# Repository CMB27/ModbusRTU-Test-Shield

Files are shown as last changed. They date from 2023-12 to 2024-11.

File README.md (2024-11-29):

# ModbusRTU Test Shield
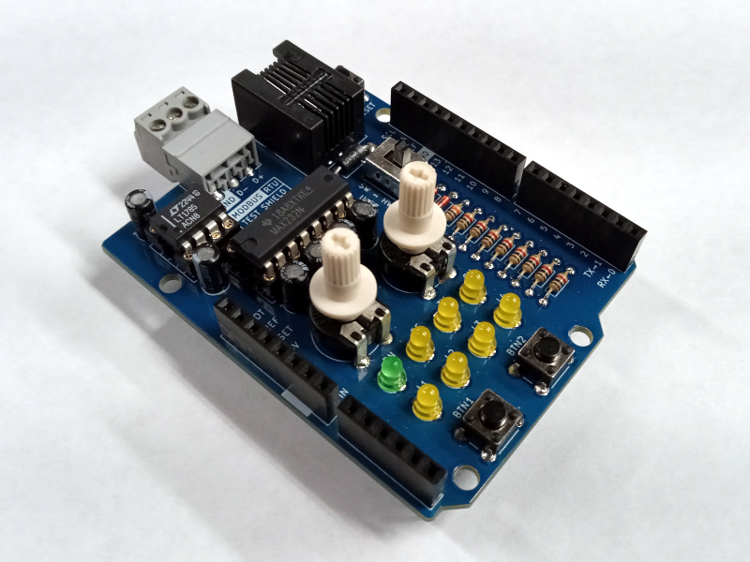
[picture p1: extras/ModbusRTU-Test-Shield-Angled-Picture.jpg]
ModbusRTU Test Shield Picture


A shield for Arduino boards that provides an RS-485 transceiver, RS-232 transceiver, and a selection of buttons, lights, and knobs.
This board was designed to aid in testing the [ModbusRTUSlave](https://github.com/CMB27/ModbusRTUSlave) and [ModbusRTUMaster](https://github.com/CMB27/ModbusRTUMaster) libraries.

- This shield is designed to work with both 5V and 3.3V Arduino boards.
- A 3-position removable screw terminal is used as the RS-485 interface.
- A RJ12 connector is used as the RS-232 inteface. The pinout of this connector is designed to make it compatible with Automation Direct products.
- The potentiomter knobs can be easily removed so you can stack other shields on top of this one.
- There is a switch to easily change between using a `HardwareSerial` port or a `SoftwareSerial` port.
- The selected serial port is connected to both the RS-485 and RS-232 transceivers, so not confugration changes are needed to switch between them.

> [!NOTE]
> This design is distributed WITHOUT ANY EXPRESS OR IMPLIED WARRANTY, INCLUDING OF MERCHANTABILITY, SATISFACTORY QUALITY AND FITNESS FOR A PARTICULAR PURPOSE.
> 
> This board is designed to use only one serial interface (RS-485 or RS-232) at a time.
> Attempting to use both at the same time is unlikely to damage the board, but could lead to unexpected behavior.

### Pinouts
#### Arduino Pin Usage
| Pin | Function | pinMode |
|-----|---|---|
| 0 | HardwareSerial RX | INPUT (Set by HardwareSerial) |
| 1 | HardwareSerial TX | OUTPUT (Set by HardwareSerial) |
| 2 | Button1 (BTN1) | INPUT_PULLUP |
| 3 | Button2 (BTN2) | INPUT_PULLUP |
| 5 | LED1 (L1) | OUTPUT |
| 6 | LED1 (L2) | OUTPUT |
| 7 | LED1 (L3) | OUTPUT |
| 8 | LED1 (L4) | OUTPUT |
| 10  | SoftwareSerial RX | INPUT (Set by SoftwareSerial) |
| 11  | SoftwareSerial TX | OUTPUT (Set by SoftwareSerial) |
| 13  | Driver Enable (DE) | OUTPUT (set by ModbusRTUSlave or ModbusRTUMaster) |
| A0  | Potentiometer1 (POT1) | INPUT |
| A1  | Potentiometer2 (POT2) | INPUT |

_Unused Pins: 4, 9, 12, A2, A3, A4, A5_

#### RS-485 Interface (J5)
| Pin | Function  | Electrical Type |
|-----|---|---|
| 1 | RS-485 D+ | Bidirectional |
| 2 | RS-485 D- | Bidirectional |
| 3 | GND | Passive |

#### RS-232 Interface (J6)
| Pin | Function  | Electrical Type |
|-----|---|---|
| 1 | GND | Passive |
| 2 | 5V | Power Output |
| 3 | RS-232 RX | Input |
| 4 | RS-232 TX | Output |
| 5 | VBUS | Power Input |
| 6 | GND | Passive |

### Documentation
- [Schematic](ModbusRTU-Test-Shield.pdf)
- [KiCAD Source Files](src)
- [STEP 3D Model](extras/ModbusRTU-Test-Shield.step)

## Components

### Circuit Board
#### Specifications
- Board Length: __68.58mm__
- Board Width: __53.34mm__
- Board Thickness: __1.6mm__
- Substrate Material: __FR4__
- Copper Layers: __2__
- Copper Thickness: __1oz__
- Soldermask Color: __Any__ (Blue Suggested)
- Smallest Hole Diameter: __0.6mm__
- Smallest Trace Width: __0.2mm__ (7.8mil)
- Smallest Trace Spacing: __0.2mm__ (7.8mil)

#### Suppliers
Below are some circuit board manufacturers I have used in the past.
Generally you will need to upload the upload the [gerber and drill files](gerbers) to their websites in a .zip folder.

- [OSH Park](https://oshpark.com) is a US based circuit board fabrication service.
  They tend to be more expensive than other manufacturers and the number of options they give you are limited (If you use this manufacturer, I hope you like purple).

- [Seeed Studio Fusion](https://www.seeedstudio.com/fusion_pcb.html) makes circuit boards in China.
  They have a lot of options when ordering; please refer to the [specifications](#specifications) above when making your choices.
  They do have a circuit board assembly service as well, but I am not especially familiar with it.

### Purchase Components

| Reference | Qty | Manufacturer | Part Number | Description | Notes |
|---|----:|---|---|---|---|
| C1-C6 | 6 | KEMET | ESS105M050AB2EA | 1uF Aluminum Electrolytic Capacitor | |
| D1-D4, D6-D8 | 7 | Würth Elektronik | 151031YS06000 | Yellow LED | |
| D5 | 1 | Würth Elektronik | 151031VS04000 | Green LED | |
| D9, D10 | 2 | Vishay | BAT43-TAP | Schottky Diode | |
| D11 | 1 | Vishay | SB260S-E3/54 | Schottky Diode | |
| J1-J4 | 1 | SparkFun Electronics | PRT-11417	 | Stacking Socket Header Kit | This kit contains all the connectors for the Arduino interface. |
| J5 | 1 | Phoenix Contact | 5434557 | 3-Position Terminal Block Plug | |
| J6 | 1 | Amphenol ICC (FCI) | 87180-066LF | RJ12 Jack | |
| R1-R8 | 8 | Stackpole Electronics  | CFM14JT1K00 | 1K Ohm Resistor | These are generic 1K Ohm resistors; smilarly sized components of the same value should work.  |
| R9 | 1 | Stackpole Electronics  | CFM14JT10K0 | 10K Ohm Resistor | This is a generic 10K Ohm resistor; a smilarly sized component of the same value should work. |
| RV1, RV2 | 2 | Piher/Amphenol | PT10MV10-103A2020-E-S | 10K Ohm Potentiometer | |
| RV1, RV2 | 2 | Piher/Amphenol | JPEPL6052INI | Potentiometer Knob | |
| SW1-SW3 | 3 | Omron | B3F-1020 | 6mm Pushbutton Switch | This is a generic 6mm pushbutton switch. Feel free to substitute. |
| SW4 | 1 | C&K | OS202011MS2QN1 | DPDT Slide Switch | |
| U1 | 1 | Texas Instruments | SN65HVD3082EP | RS-485 Half-Duplex Transceiver | |
| U2 | 1 | Texas Instruments | MAX232N | RS-232 Transceiver | |
| XJ5 | 1 | Phoenix Contact | 5430438 | 3-Position Terminal Block Header | |
| XU1 | 1 | Assmann WSW Components | AR 08-HZL/01-TT | 8-Position DIP Socket | |
| XU2 | 1 | Assmann WSW Components | AR 16-HZL/01-TT | 16-Position DIP Socket | |

You may also want termination resistors for RS-485; 120 Ohms is a common value.

#### Suppliers
Below are some electronics suppliers I have used in the past:

- [Digi-Key](https://www.digikey.com/) is my usual go-to supplier for electronic components.
  Their website makes it pretty easy to sort through parts.

- [Mouser](https://www.mouser.com/) is very similar to Digi-Key in a lot of ways.
  They sometimes have better pricing, and they have excellent customer support.

- [Newark](https://www.newark.com/) tends to have a bit different selection than Digi-Key and Mouser, especially in the area of connectors.

- [Octopart](https://octopart.com/) is not a supplier per se; it is essenitally an electronic component search engine.
  This can be a very helpful tool when looking for parts, especially somewhat unusual ones, like extended socket headers.

All of these suppliers have a feature on their respective websites where you can upload a spreadsheet file, such as [ModbusRTU-Test-Shield-BOM.csv](ModbusRTU-Test-Shield-BOM.csv), to populate the cart or find parts.

## Assembly

### Tools and Supplies
| Item | Optional | Notes |
|---|---|---|
| Soldering Iron | No | Make sure you use a good quality soldering iron. A poor quality soldering iron will give you a miserable soldering experience. |
| Flush Cutters | No | These are used to trim component leads. |
| Flux Core Solder  | No | Leaded solder is easier to work with, but lead-free solder is better for the environment. |
| Solder Flux | Yes | Extra flux will make the solder flow better. I don't usually use it when through-hole soldering, but it can be helpful. |
| Solder Wick | Yes | This is used to remove solder from places you don't want it. |
| Solder Sucker | Yes | If you need to de-solder a component, this, along with solder wick, is the tool you want. This can quickly remove most of the solder from a joint. |
| Arduino Shield | Yes | This can be used to hold the stacking socket headers in place while being assembled. |
| Isopropyl Alcohol | Maybe | This is used to remove flux. It is not needed if you are using no-clean flux. |
| Dish Soap | Maybe | This is used to remove flux residue. It is not needed if you are using no-clean flux. |

**Note on Flux**  
Traditional flux if left on the assembled circuit board could cause some serious issues.
It can potentially cause shorts or significant [parasitic capacitance](https://en.wikipedia.org/wiki/Parasitic_capacitance).
It is also somewhat corrosive and can, over time, damage your circuit board.
This sort of flux must be cleaned off the board after assembly.  
To address these issues there are no-clean fluxes, that can be left on the circuit board assembly and are unlikly to cause these issues.
There are also water-soluble fluxes that can be cleaned off with hot water, though I have found that some isopropyl alcohol can speed up the process.
There are also fluxes that are both no-clean and water soluble; this is what I like to use.

### Assembly Steps
Except for the socketed parts, all the components are placed on the front side of the board and solderd on the back side of the board.
These steps go through soldering each component, starting with the shortest.  
The [interactive HTML BOM](https://github.com/CMB27/ModbusRTU-Test-Shield/blob/main/extras/ModbusRTU-Test-Shield-interactive-BOM.html) may be helpful to you in this process.
It graphically shows where each component goes on the board.
You will need to download it in order to view it; GitHub does not render HTML files in repositories.

<details><summary><strong>1. R1-R9 (Resistors) and D9-D11 (Diodes)</strong></summary>
  <blockquote>

Two different resistor values used.  
The 8 resistors furthest from the diode footprints (R1-R8) are 1K Ohm resistors.
The color code on these will be orange, orange, brown, gold.  
The resistor right next to the diode footprints (R9) is a 10K Ohm resistor.
The color code on this resistor will be brown, black, orange, gold.

Two different diode parts are used on this board.  
The smaller signal diodes (D9, D10) are placed next to the resistors.  
The larger power diode (D11) is placed right next to the RJ12 footprint.

- Bend the compnent leads so that the parts will fit in their footprints.
- Place the components.
- Bend the leads on the backside of the board to hold them in place.
- On the backside of the board, solder the leads to the pads.
- Trim the leads using the flush cutters.

  </blockquote>
</details>

<details><summary><strong>2. XU1-XU2 (Integrated Circuit Sockets)</strong></summary>
  <blockquote>

*You will likely need to install the sockets one at a time.*

- Place the socket so that the notch matches up with the notch shown on the circuit board.
- Flip the board over and solder two pins in opposite corners of the socket.
- Check that the socket is straight and seated correctly on the board.
  If everything looks good proceed, otherwise, reheat your solder joints one at a time and adjust the socket position.
- Solder the remaining pins.

  </blockquote>
</details>

<details><summary><strong>3. SW1-SW3 (Push-button Switches)</strong></summary>
  <blockquote>

- Place the switches; these have kinked leads, so they should stay once placed.
- Turn the board over and solder the leads to the board.

  </blockquote>
</details>

<details><summary><strong>4. D1-D8 (LEDs)</strong></summary>
  <blockquote>

The `ON` LED (D5), is green.  
All the other LEDs (D1-D4, D6-D8) are yellow.

- Place the LEDs in their respective footprints with the short lead (cathode) going through the squarish pad.
- Bend the leads on the backside of the board to hold them in place.
- Solder the leads.
- Trim the leads.

  </blockquote>
</details>

<details><summary><strong>5. RV1-RV2 (Potentiometers)</strong></summary>
  <blockquote>

*You will likely need to install the potentiometers one at a time.*

- Place the potentiometer.
- Flip the board over and solder the pins.

  </blockquote>
</details>

<details><summary><strong>6. XJ5 (Terminal Block Header)</strong></summary>
  <blockquote>

- Place the terminal block header.
- Solder one of the pins.
- Check the placement of the header; reheat the solder joint and make adjustments if necessary.
- Solder the remaining pins.

  </blockquote>
</details>

<details><summary><strong>7. C1-C6 (Capacitors)</strong></summary>
  <blockquote>

- Place the capacitors, ensuring the `-` symbol on the capacitors is facing away from the `+` symbol on the board.
  For capacitors, the positive lead goes through the squarish pad and the negative lead goes through the circular pad.
- Bend the leads on the backside of the board to hold the capacitors in place.
- Solder the leads.
- Trim the leads.

  </blockquote>
</details>

<details><summary><strong>8. J1-J4 (Arduino UNO Interface)</strong></summary>
  <blockquote>

- If you have a shield for the Arduino UNO, place the stacking socket headers on its pins, then place the socket header pins through the holes in the circuit board.
  This will make it easier and faster to install the sockets.
  If you don't have a shield you will likely need to install the sockets one at a time.
- Carefully flip the board over the board, holding the socket headers in place.
- Tack solder the end pins of each socket header.
- Check the placement of the headers and make adjustments as needed.
- Solder the remaining pins.
- If you used a shield, remove it now.

  </blockquote>
</details>

<details><summary><strong>9. SW4 (Slide Switch)</strong></summary>
  <blockquote>

- Place the slide switch.
- Flip the board over and solder two of the smaller pins in opposite corners.
- Check the placement of the switch, making adjustments as needed.
- Solder the remaining pins.

  </blockquote>
</details>

<details><summary><strong>10. J6 (RJ12 Jack)</strong></summary>
  <blockquote>

- Place the jack; it should snap in place.
- Flip the board over and solder all the pins.

  </blockquote>
</details>

<details><summary><strong>11. Clean Flux Off Board</strong></summary>
  <blockquote>

*If you used no-clean flux, you can skip this step.*

This step was written with water-soluble flux in mind.  
If you used non-water-soluble flux, you may need to use a different cleaning process.

- Use isopropyl alcohol with a toothbrush to remove the bulk of the flux.
- Clean the board with dish soap and warm water using the same toothbrush.
- Dry the board thoroughly. I like to use compressed air for this step.

  </blockquote>
</details>

<details><summary><strong>12. U1-U2 (Integrated Circuits)</strong></summary>
  <blockquote>

- Carefully bend the pins on the ICs so that they are straight up and down.
  I usually use a table surface to bend all the leads on one side of the chip at a time.
- Carefully instert the chips into the sockets on the board.
  Make sure you don't crumple any pins in this process.

  </blockquote>
</details>

<details><summary><strong>13. Finishing Touches</strong></summary>
  <blockquote>

- Insert the screw terminal block (J5) into its header.
- Insert the potentiometer knobs.

  </blockquote>
</details>

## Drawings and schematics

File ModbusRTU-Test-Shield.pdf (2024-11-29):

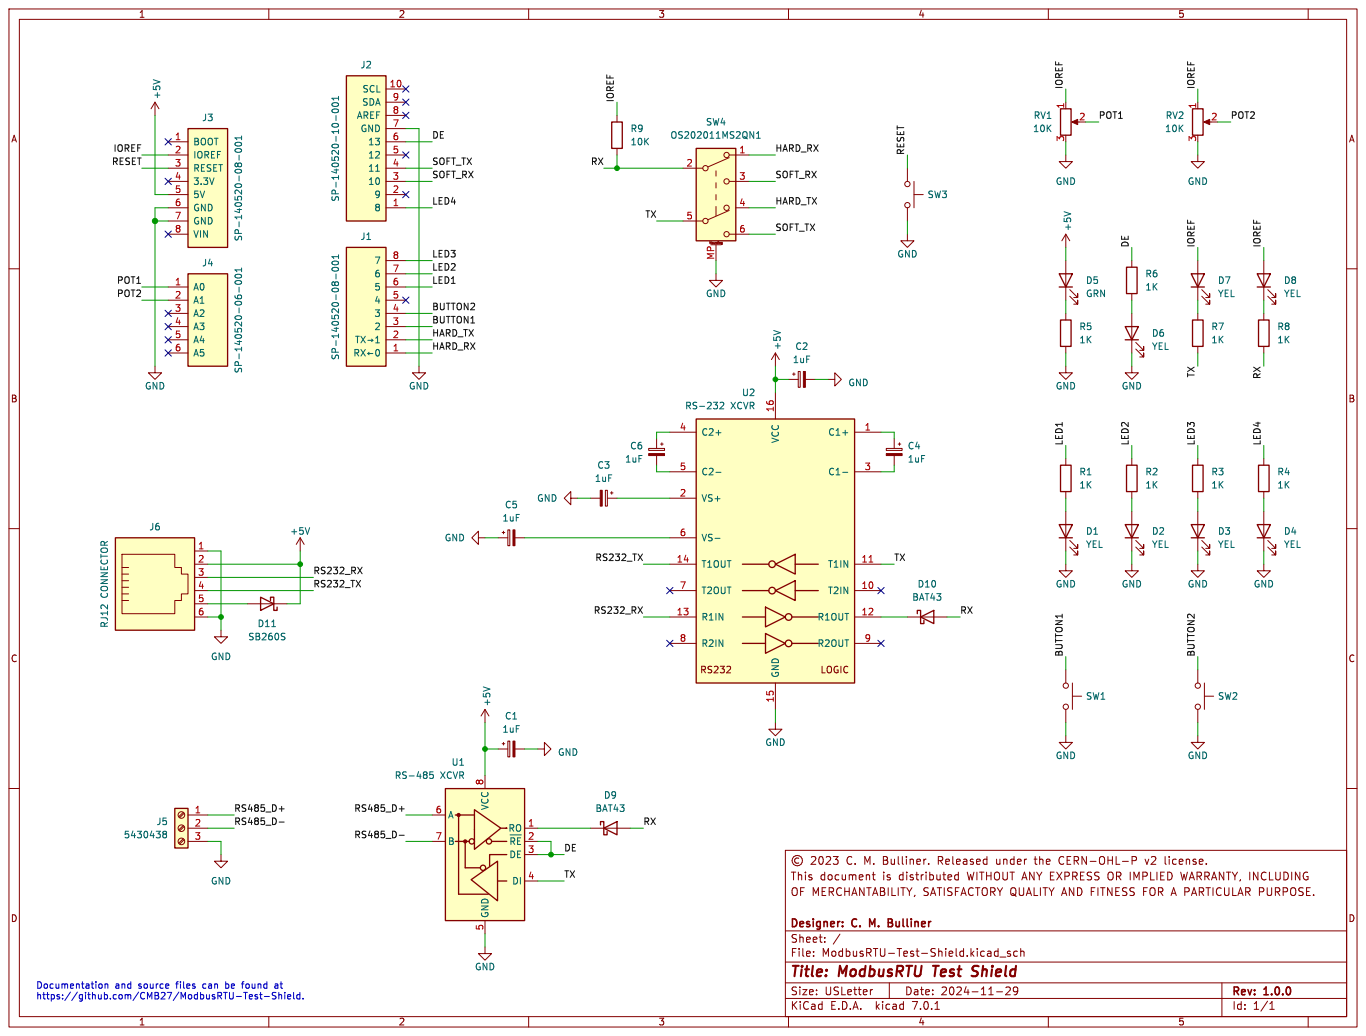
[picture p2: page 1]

Id: 1/1 Title: ModbusRTU Test Shield

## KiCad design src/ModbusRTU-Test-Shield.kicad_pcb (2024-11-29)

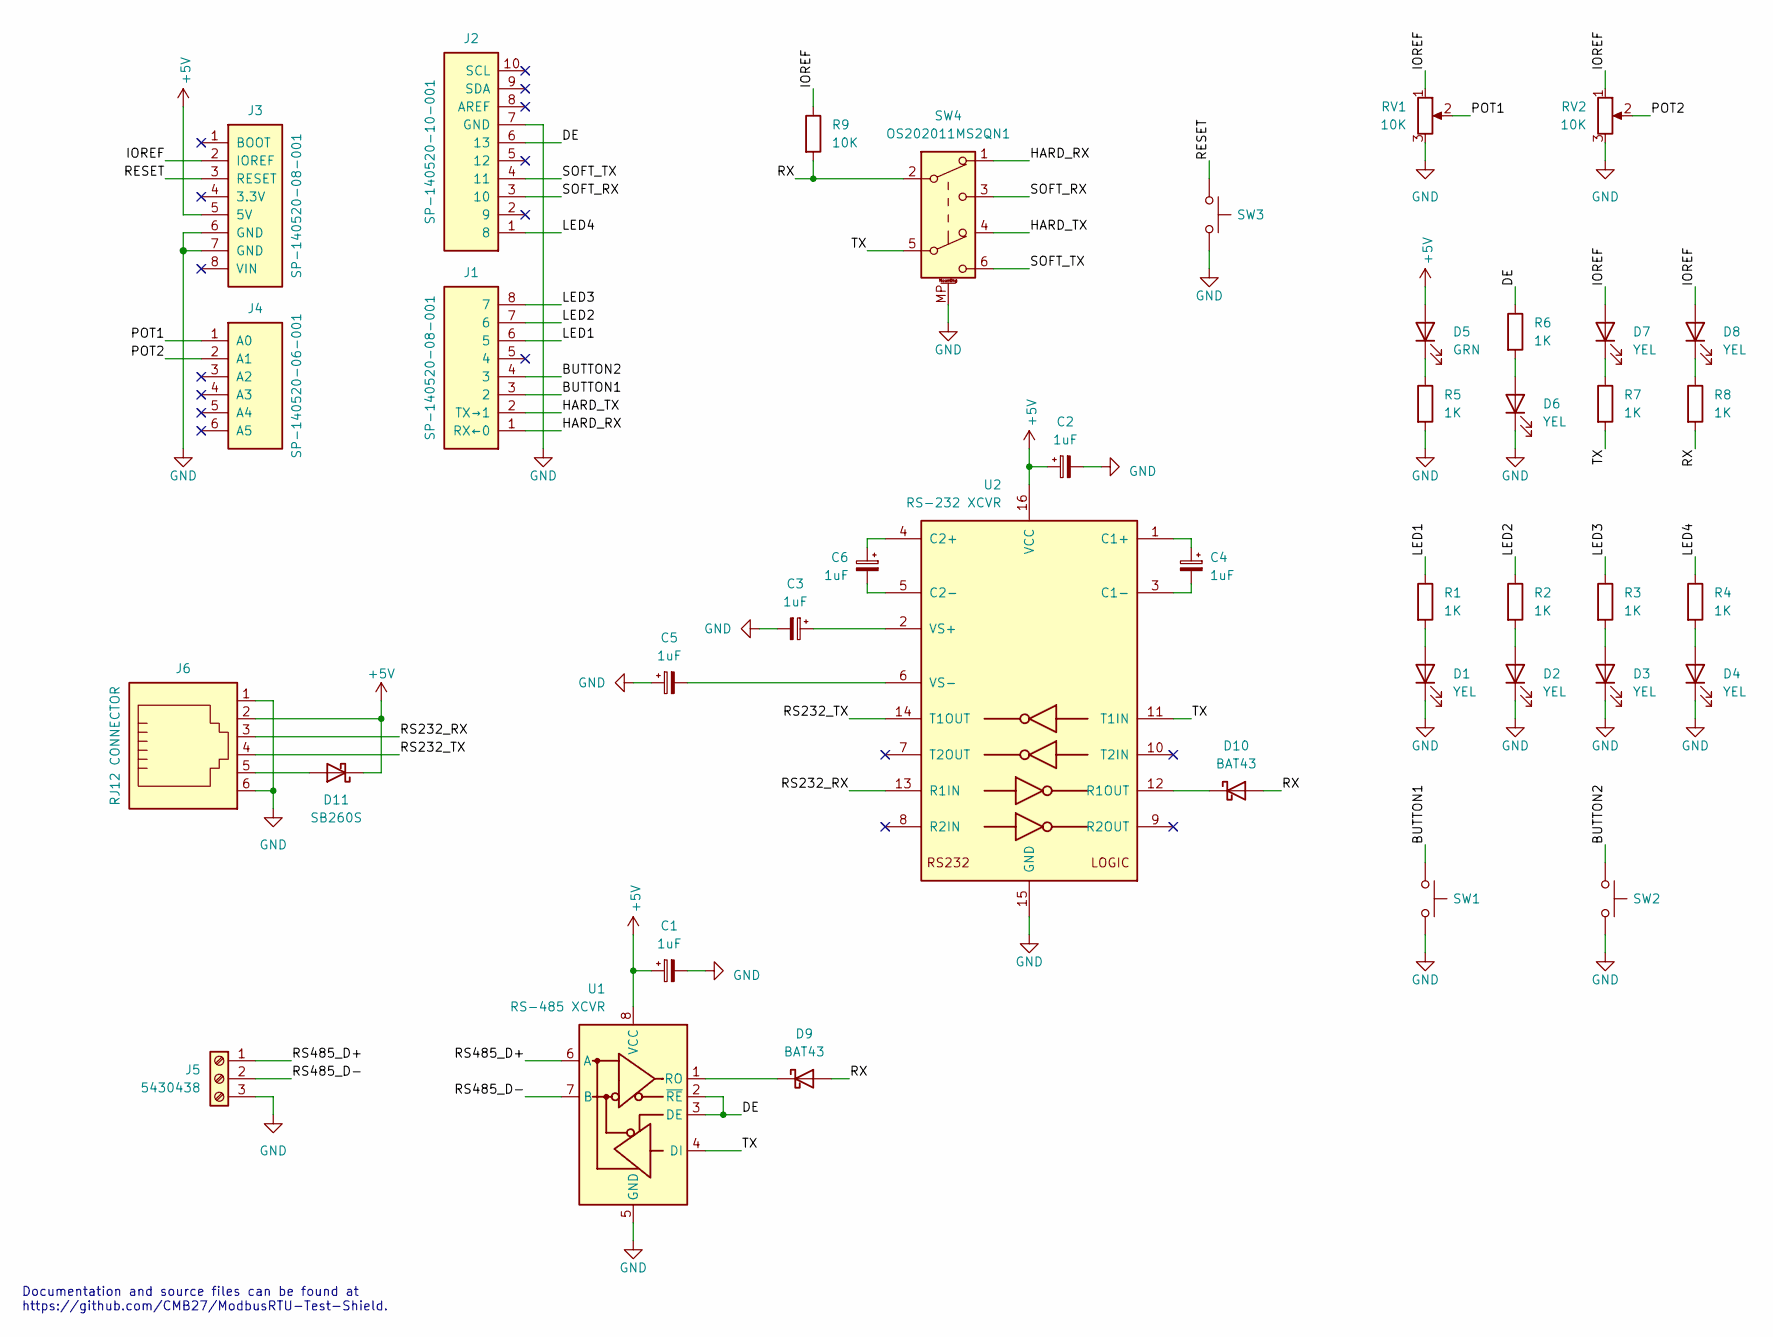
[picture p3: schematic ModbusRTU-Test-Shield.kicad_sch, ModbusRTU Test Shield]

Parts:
C1, C2, C3, C4, C5, C6: 1uF; CP_Radial_D4.0mm_P1.50mm; Part Number ESS105M050AB2EA
D1, D2, D3, D4, D6, D7, D8: YEL; LED_D3.0mm; Part Number 151031YS06000
D5: GRN; LED_D3.0mm; Part Number 151031VS04000
D9, D10: BAT43; D_DO-35_SOD27_P7.62mm_Horizontal; Part Number BAT43-TAP
D11: SB260S; D_DO-41_SOD81_P10.16mm_Horizontal; Part Number SB260S-E3/54
J1: SP-140520-08-001; PinSocket_1x08_P2.54mm_Vertical_UNO_Digital_1; Part Number SP-140520-08-001
J2: SP-140520-10-001; PinSocket_1x10_P2.54mm_Vertical_UNO_Digital_2; Part Number SP-140520-10-001
J3: SP-140520-08-001; PinSocket_1x08_P2.54mm_Vertical_UNO_Power; Part Number SP-140520-08-001
J4: SP-140520-06-001; PinSocket_1x06_P2.54mm_Vertical_UNO_Analog; Part Number SP-140520-06-001
J5: 5430438; PhoenixContact_BCH-350H-3_RS485; Part Number 5430438
J6: RJ12 CONNECTOR; FCI_54601-906WPLF; Part Number 87180-066LF
R1, R2, R3, R4, R5, R6, R7, R8: 1K; R_Axial_DIN0204_L3.6mm_D1.6mm_P7.62mm_Horizontal; Part Number CFM14JT1K00
R9: 10K; R_Axial_DIN0204_L3.6mm_D1.6mm_P7.62mm_Horizontal; Part Number CFM14JT10K0
RV1, RV2: 10K; Potentiometer_Piher_PT-10-V10_Vertical; Part Number PT10MV10-103A2020-E-S
SW1: BUTTON1; SW_PUSH_6mm; Part Number B3F-1020
SW2: BUTTON2; SW_PUSH_6mm; Part Number B3F-1020
SW3: RESET; SW_PUSH_6mm; Part Number B3F-1020
SW4: OS202011MS2QN1; SW_CK_OS202011MS2Qx1_DPDT; Part Number OS202011MS2QN1
U1: RS-485 XCVR; DIP-8_W7.62mm_Socket; Part Number SN65HVD3082EP
U2: RS-232 XCVR; DIP-16_W7.62mm_Socket; Part Number MAX232N

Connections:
+5V: C1.1, C2.1, D5.2 (A), D11.1 (K), J3.5 (5V), J6.2, U1.8 (VCC), U2.16 (VCC)
/BUTTON1: J1.3 (2), SW1.1
/BUTTON2: J1.4 (3), SW2.1
/DE: J2.6 (13), R6.1, U1.2 (~RE), U1.3 (DE)
/HARD_RX: J1.1 (RX←0), SW4.1 (A)
/HARD_TX: J1.2 (TX→1), SW4.4 (A)
/IOREF: D7.2 (A), D8.2 (A), J3.2 (IOREF), R9.1, RV1.1, RV2.1
/LED1: J1.6 (5), R1.1
/LED2: J1.7 (6), R2.1
/LED3: J1.8 (7), R3.1
/LED4: J2.1 (8), R4.1
/POT1: J4.1 (A0), RV1.2
/POT2: J4.2 (A1), RV2.2
/RESET: J3.3 (RESET), SW3.1
/RS232_RX: J6.3, U2.13 (R1IN)
/RS232_TX: J6.4, U2.14 (T1OUT)
/RS485_D+: J5.1, U1.6 (A)
/RS485_D-: J5.2, U1.7 (B)
/RX: D9.2 (A), D10.2 (A), R8.2, R9.2, SW4.2 (B)
/SOFT_RX: J2.3 (10), SW4.3 (C)
/SOFT_TX: J2.4 (11), SW4.6 (C)
/TX: R7.2, SW4.5 (B), U1.4 (DI), U2.11 (T1IN)
GND: C1.2, C2.2, C3.2, C5.1, D1.1 (K), D2.1 (K), D3.1 (K), D4.1 (K), D6.1 (K), J2.7 (GND), J3.6 (GND), J3.7 (GND), J5.3, J6.1, J6.6, R5.2, RV1.3, RV2.3, SW1.2, SW2.2, SW3.2, SW4.MP (MountPin), U1.5 (GND), U2.15 (GND)
unnamed: D1.2 (A), R1.2
unnamed: D2.2 (A), R2.2
unnamed: D3.2 (A), R3.2
unnamed: D4.2 (A), R4.2
unnamed: D5.1 (K), R5.1
unnamed: D6.2 (A), R6.2
unnamed: D7.1 (K), R7.1
unnamed: D8.1 (K), R8.1
unnamed: D9.1 (K), U1.1 (RO)
unnamed: D10.1 (K), U2.12 (R1OUT)
unnamed: D11.2 (A), J6.5
unnamed: C4.1, U2.1 (C1+)
unnamed: C4.2, U2.3 (C1-)
unnamed: C6.1, U2.4 (C2+)
unnamed: C6.2, U2.5 (C2-)
unnamed: C3.1, U2.2 (VS+)
unnamed: C5.2, U2.6 (VS-)

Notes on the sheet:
Documentation and source files can be found at https://github.com/CMB27/ModbusRTU-Test-Shield.

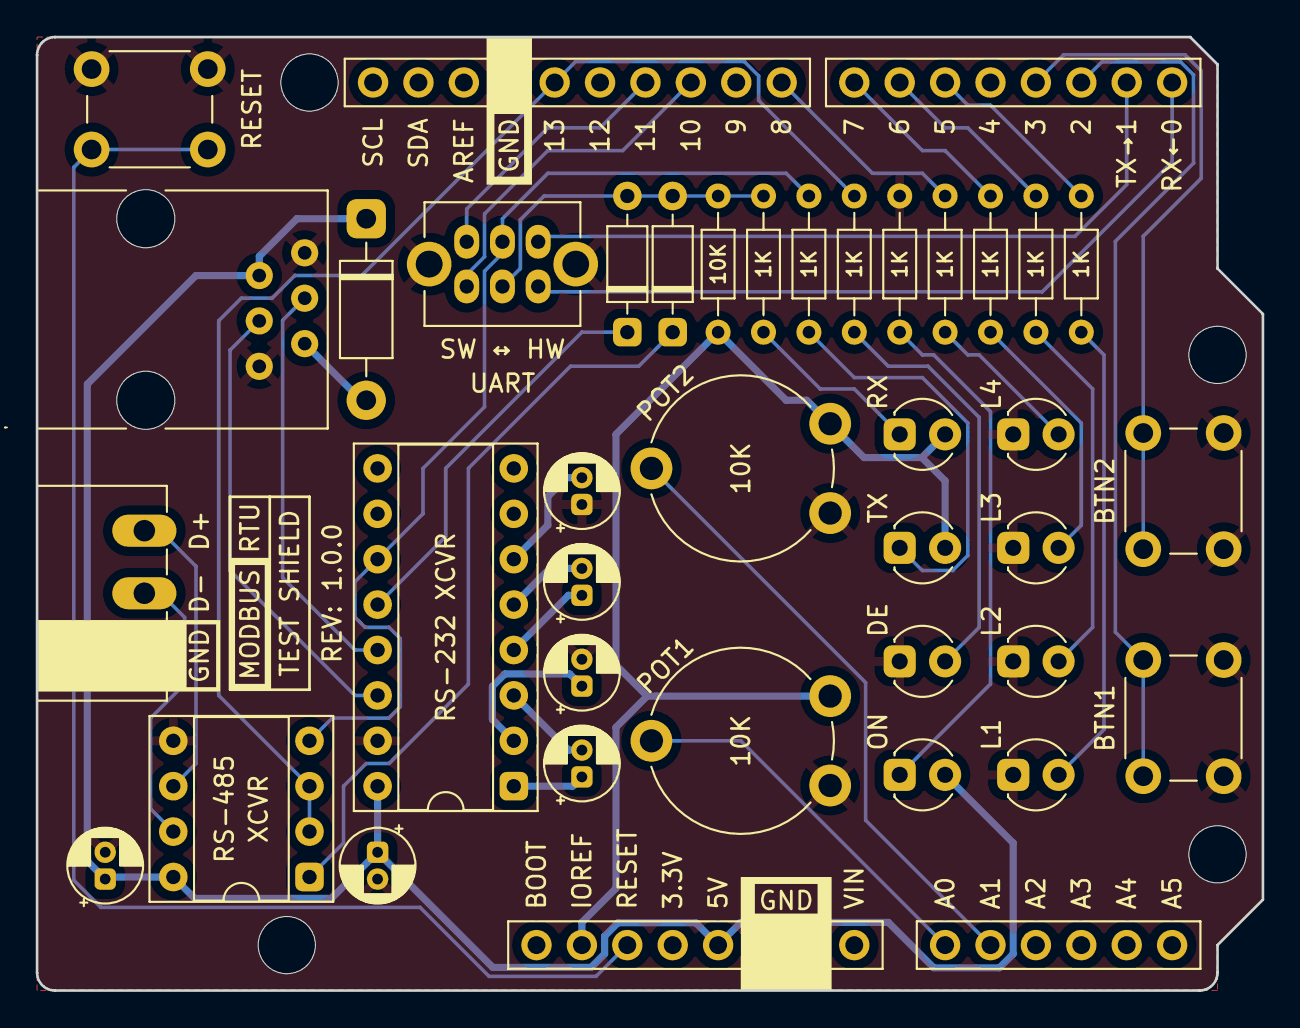
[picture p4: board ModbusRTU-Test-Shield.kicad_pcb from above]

Board: 2 copper layers, 68.6 x 53.3 mm, 44 parts (0 on the bottom side), 40 nets.

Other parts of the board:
MH1, MH2, MH3, MH4: MountingHole_3.2mm

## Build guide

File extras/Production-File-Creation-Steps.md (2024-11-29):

# Production File Creation Steps
These steps are for use with the [ModbusRTU Test Shield source files](https://github.com/CMB27/ModbusRTU-Test-Shield/tree/main/src).

## Schematic Editor

### Check Date and Revision
- Click on the `Settings for paper size and title block info` button or `File/Page Settings...`
- In the `Page Settings` window:
  - Click on the `<<<` button to set the `Issue Date` to the current date
  - Make sure the `Revision` is set correctly
  - Click `OK`

### Generate PDF of Schematic
- Click on the `Plot` button or `File/Plot...`
- In the `Plot Schematic Options` window:  
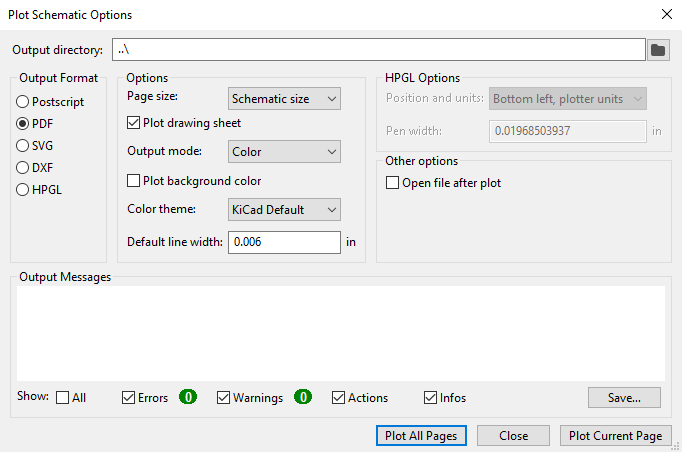
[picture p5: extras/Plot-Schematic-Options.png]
Plot Schematic Options
  
  - Set the output directory to `../` or in Windows `..\`
  - Set the output format to `PDF`
  - In `Options`:
    - Set the `Page size` to `Schematic size`
    - Make sure the box to `Plot drawing sheet` is checked
    - Set the `Output mode` to `Color`
    - Make sure the box to `Plot background color` is not checked
    - Set the `Color theme` to `KiCad Default`
    - Set the `Default line width` to `0.006in` or `0.1524mm`
  - In `Other options`, make sure the box to `Open file after plot` is not checked
  - Click `Plot Current Page`
  - Click `Close`

## PCB Editor

### Check Date and Revision
- Click on the `Settings for paper size and title block info` button or `File/Page Settings...`
- In the `Page Settings` window:
  - Click on the `<<<` button to set the `Issue Date` to the current date
  - Make sure the `Revision` is set correctly
  - Click `OK`

### Generate Gerber and Drill Files
- Click on the `Plot` button or `File/Plot...`
- In the `Plot` window:  
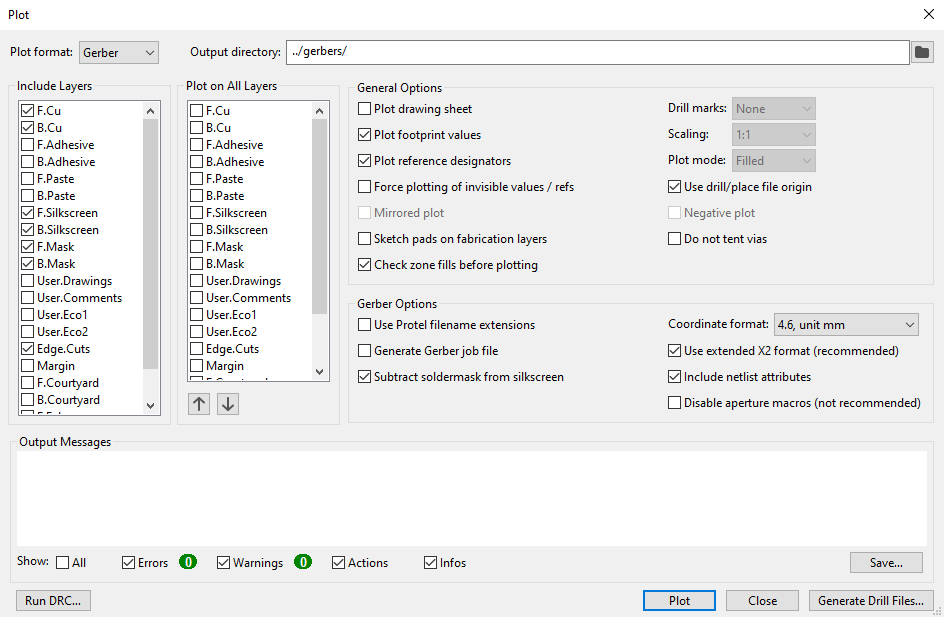
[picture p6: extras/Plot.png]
Plot
  
  - Set `Plot Format` to `Gerber`
  - Set `Output directory` to `../gerbers/`
  - In `Include Layers`, make sure only the following boxes checked:
    - `F.Cu`
    - `B.Bu`
    - `F.Silkscreen`
    - `B.Silkscreen`
    - `F.Mask`
    - `B.Mask`
    - `Edge.Cuts`
  - In `Plot on All Layers`, make sure none of the boxes are checked
  - In `General Options`, make sure only the following boxes are checked:
    - `Plot footprint values`
    - `Plot reference designators`
    - `Check zone fills before plotting`
    - `Use drill/place file origin`
  - In `Gerber Options`:
    - Set `Coordinate format` to `4.6, unit mm`
    - Make sure only the following boxes are checked:
      - `Subtract soldermask from silkscreen`
      - `Use extended X2 format`
      - `Include netlist attributes`
  - Click `Plot`
  - Click `Generate Drill Files...`
  - In the `Generate Drill Files` window:  
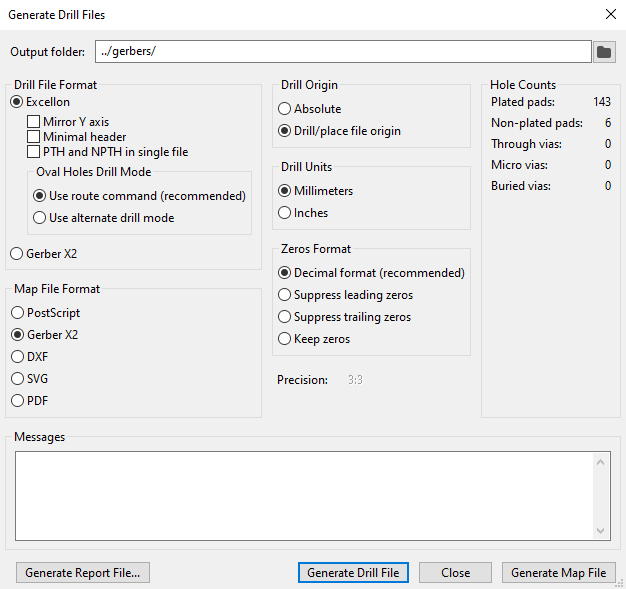
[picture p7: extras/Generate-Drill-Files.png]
Generate Drill Files
    
    - Set `Output folder` to `../gerbers/`
    - In `Drill File Format`:
      - Select `Excellon`
      - Make sure none of the boxes are checked
      - In `Oval Holes Drill Mode`, select `Use route command`
    - In `Drill Origin`, select `Drill/place file origin`
    - In `Drill Units`, select `Millimeters`
    - In `Zeros Format`, select `Decimal format`
    - Click `Generate Drill File`
    - Click `Close`
  - Click `Close`

### Generate STEP File
- Click `File/Export/STEP...`
- In the `Export STEP` window:  
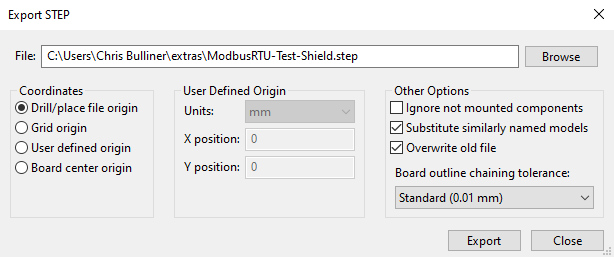
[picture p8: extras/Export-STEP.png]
Export STEP
  
  - Set `File` to `../extras/ModbusRTU-Test-Shield.step`
  - In `Coordinates`, select `Drill/place file origin`
  - In `Other Options`:
    - Make sure only the following boxes are checked:
      - `Substitute similarly named models`
      - `Overwrite old file`
    - Set `Board outline chaining tolerance` to `Standard (0.01mm)`
  - Click `Export`
  - In the `STEP Export` window, once the export has completed, click `OK`

### Generate Interactive HTML BOM
- Click on the `Generate Interactive HTML BOM` button
- The appropriate settings should automatically load
- Click `Generate BOM`

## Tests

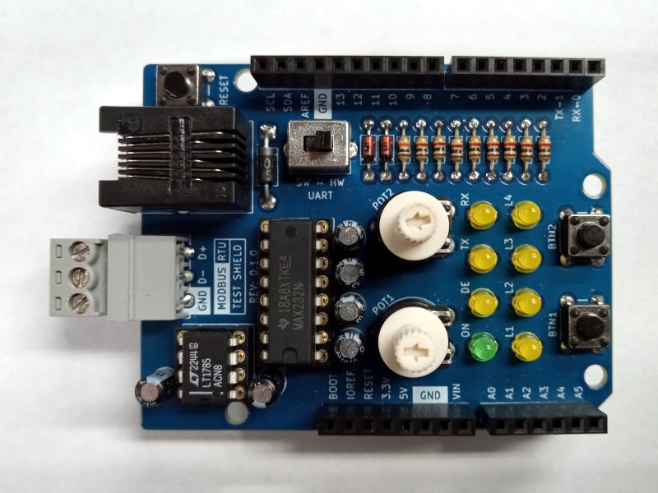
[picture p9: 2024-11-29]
extras/ModbusRTU-Test-Shield-Top-Picture.jpg

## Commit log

2023-12-10 Started circuit board layout.
    [ModbusRTU-Test-Shield.kicad_pcb, ModbusRTU-Test-Shield.kicad_sch]
2023-12-10 Completed first draft.
    [ModbusRTU-Test-Shield.kicad_pcb, ModbusRTU-Test-Shield.kicad_sch]
2023-12-11 Added RS-232 on an RJ12 connector. Completed second draft.
    [ModbusRTU-Test-Shield.kicad_pcb, ModbusRTU-Test-Shield.kicad_sch]
2023-12-14 Added some 3D models. Created project footprints for RJ12 and screw terminal connectors. Placed and locked RJ12 and screw terminal connector.
    [ModbusRTU-Test-Shield.kicad_pcb, ModbusRTU-Test-Shield.kicad_sch]
2023-12-16 Refined button footprints. Updated and refined potentiometer footprints and models.
    [ModbusRTU-Test-Shield.kicad_pcb, ModbusRTU-Test-Shield.kicad_sch]
2023-12-17 Added model and footprint for DPDT slide switch.
2023-12-17 Changed the 3D model used for the socket/header of the screw terminal.
2023-12-17 Updated the schematic and board to use the new footprints and models.
    [ModbusRTU-Test-Shield.kicad_pcb, ModbusRTU-Test-Shield.kicad_sch]
2023-12-17 Removed the unused models and footprints from project_libraries.
2023-12-19 Completed third draft.
    [ModbusRTU-Test-Shield.kicad_pcb, ModbusRTU-Test-Shield.kicad_sch]
2023-12-22 Completed fourth draft.
    [ModbusRTU-Test-Shield.kicad_pcb, ModbusRTU-Test-Shield.kicad_sch]
2023-12-26 Created a 3D model of the capacitor.
2023-12-26 Copied the used 3D models from the KiCad library into project_libraries/Project_3DModels.3dshapes. Updated Project_3DModels_notes.
2023-12-26 Put all of the used symbols into project_libraries/Project_Symbols.kicad_sym.
2023-12-26 Updated the main source files.
    [ModbusRTU-Test-Shield.kicad_pcb, ModbusRTU-Test-Shield.kicad_sch]
2023-12-26 Updated the source files.
    [ModbusRTU-Test-Shield.kicad_pcb, ModbusRTU-Test-Shield.kicad_sch]
2023-12-26 Generated gerber and drill files.
    [ModbusRTU-Test-Shield-B_Cu.gbr, ModbusRTU-Test-Shield-B_Mask.gbr, ModbusRTU-Test-Shield-B_Silkscreen.gbr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]
2023-12-26 Generated some renderings of the circuit board assembly.
2023-12-26 Generated a 3D model of the circuit board assembly.
2023-12-26 Generated an interactive html BOM.
2023-12-26 Generated a PDF of the schematic.
2023-12-26 Created the BOM.
    [ModbusRTU-Test-Shield-BOM.csv]
2023-12-26 Updated src/.gitignore to ignore interactive BOM generation settings files.
2023-12-26 Added the revision number to the schematic.
    [ModbusRTU-Test-Shield.kicad_sch]
2023-12-27 Created and tested production_file_creation_steps.
    [ModbusRTU-Test-Shield-B_Cu.gbr, ModbusRTU-Test-Shield-B_Mask.gbr, ModbusRTU-Test-Shield-B_Silkscreen.gbr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]
2023-12-27 Improved the placement of a value and reference in the schematic.
    [ModbusRTU-Test-Shield.kicad_sch]
2023-12-28 Made several cosmetic improvements to the schematic and board. Changed the revision from 0.0.1 to 0.0.2.
    [ModbusRTU-Test-Shield-B_Cu.gbr, ModbusRTU-Test-Shield-B_Mask.gbr, ModbusRTU-Test-Shield-B_Silkscreen.gbr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]
2023-12-28 Update README.md
    Added Tools and Supplies sub-section to Assembly section.
2023-12-29 Update README.md
    Added assembly steps.
2024-01-06 Made some changes based on build.
    [ModbusRTU-Test-Shield-BOM.csv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]
2024-11-29 Updated board to 1.0.0. Changed out RJ12 connector for one that is not obsolete. Changed out RS-485 tranceiver for a less expensive model.
    [ModbusRTU-Test-Shield-BOM.csv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]

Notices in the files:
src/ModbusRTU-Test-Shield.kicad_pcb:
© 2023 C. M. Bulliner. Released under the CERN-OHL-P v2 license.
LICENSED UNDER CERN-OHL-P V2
